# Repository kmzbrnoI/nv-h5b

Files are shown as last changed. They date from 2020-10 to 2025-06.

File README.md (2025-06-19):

NV-H5B
======

NV-H5B is a [S-COM](https://www.mtb-model.com/elektro/s-com.htm) receiver based
on [NV-7B](https://www.mtb-model.com/elektro/s-com-nav.htm). It is mounted
to the socket of a signal and displays signal code according to the received code
on data wire.

This repository contains KiCad schematics & pcb layout design as well as MCU
firmware source code.

## Basic features

 * 5 V power supply.
 * Mechanical compatibility with [NV-7D](https://www.mtb-model.com/elektro/s-com-nav.htm).
 * Receives [standard S-COM protocol](https://www.mtb-model.com/elektro/s-com.htm).
 * Separate resistor for each LED to unify brightness.
 * ATtiny25 main MCU.
 * Opensource & openhardware design.
 * [Supported signals (CZ)](signals.md).

## Recommended resistor values

### AŽD 70 signals by Josef Němeček

* Yellow: 4k7
* Red: 10k
* White: 22k
* Green: 2k2
* Blue: 22k

### AŽD 65 signals by Mr. Dvořáček (Pečky)

* Yellow: 1k
* Red: 10k
* White: 22k
* Green: 1k
* Blue: 47k

## Authors

 * [Jan Horacek](mailto:jan.horacek@kmz-brno.cz)

## License

PCBs are provided under [Creative Commons Attribution-ShareAlike 4.0
License](https://creativecommons.org/licenses/by-sa/4.0/) as openhardware
project. You may download any data, contribute to the project, create PCB
yourself or even sell it yourself.

Source code is provided under the [Apache License v2.0
](https://www.apache.org/licenses/LICENSE-2.0).

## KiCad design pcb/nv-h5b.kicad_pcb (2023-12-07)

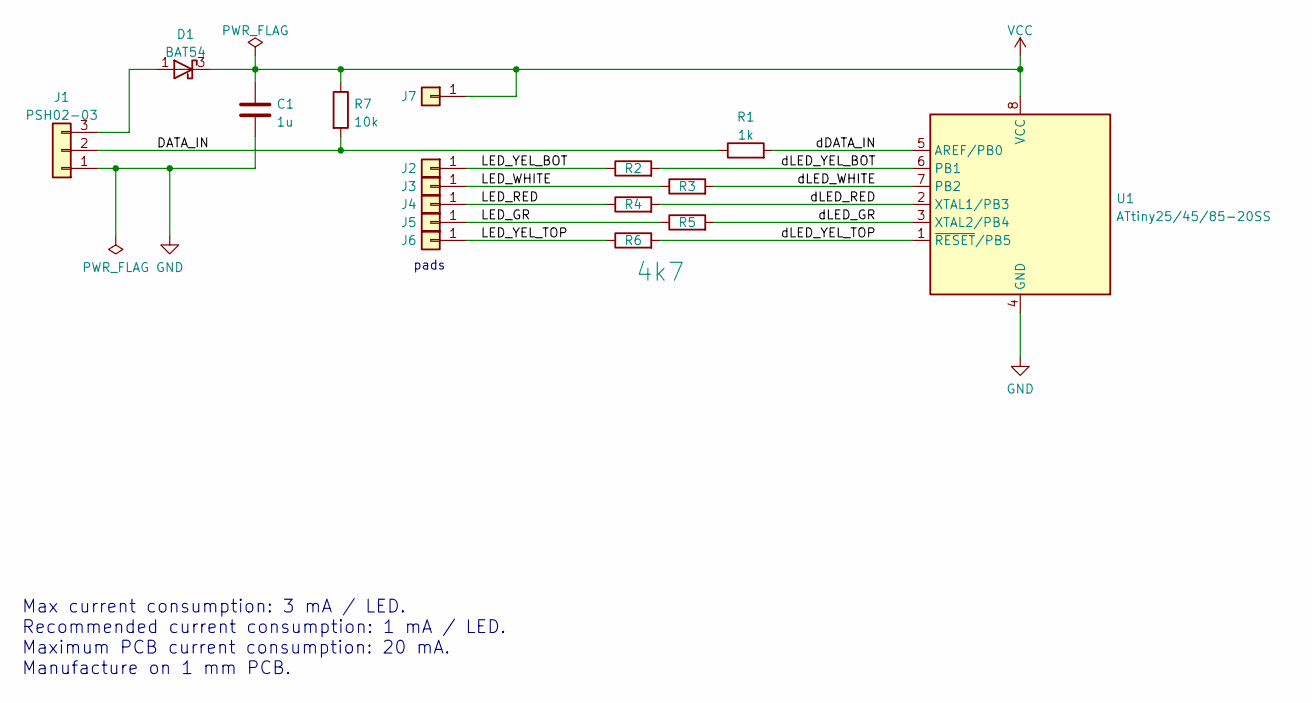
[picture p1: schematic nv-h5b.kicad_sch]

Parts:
C1: 1u; C_0805_2012Metric
D1: BAT54; SOT-23
J1: PSH02-03; PinHeader_1x03_P2.54mm_Horizontal
J2, J3, J4, J5, J6, J7: Conn_01x01; TestPoint_Keystone_5015_Micro-Minature
R1: 1k; R_0805_2012Metric
R2, R3, R4, R5, R6: 4k7; R_0805_2012Metric
R7: 10k; R_0805_2012Metric
U1: ATtiny25/45/85-20SS; SOIC-8_3.9x4.9mm_P1.27mm

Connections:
/DATA_IN: J1.2, R1.1, R7.2
/LED_GR: J5.1, R5.1
/LED_RED: J4.1, R4.1
/LED_WHITE: J3.1, R3.1
/LED_YEL_BOT: J2.1, R2.1
/LED_YEL_TOP: J6.1, R6.1
/dDATA_IN: R1.2, U1.5 (AREF/PB0)
/dLED_GR: R5.2, U1.3 (XTAL2/PB4)
/dLED_RED: R4.2, U1.2 (XTAL1/PB3)
/dLED_WHITE: R3.2, U1.7 (PB2)
/dLED_YEL_BOT: R2.2, U1.6 (PB1)
/dLED_YEL_TOP: R6.2, U1.1 (~RESET/PB5)
GND: C1.2, J1.1, U1.4 (GND)
unnamed: D1.1 (A), J1.3
VCC: C1.1, D1.3 (K), J7.1, R7.1, U1.8 (VCC)

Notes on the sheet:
Max current consumption: 3 mA / LED. Recommended current consumption: 1 mA / LED. Maximum PCB current consumption: 20 mA. Manufacture on 1 mm PCB.
pads

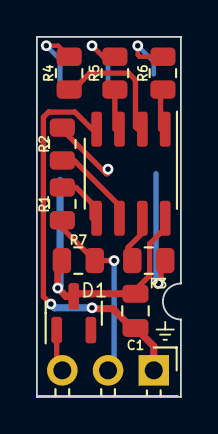
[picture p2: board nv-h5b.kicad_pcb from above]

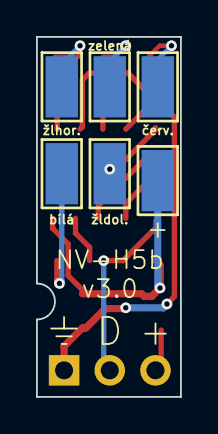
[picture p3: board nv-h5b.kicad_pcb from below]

Board: 2 copper layers, 8.0 x 20.0 mm, 17 parts (6 on the bottom side), 15 nets.

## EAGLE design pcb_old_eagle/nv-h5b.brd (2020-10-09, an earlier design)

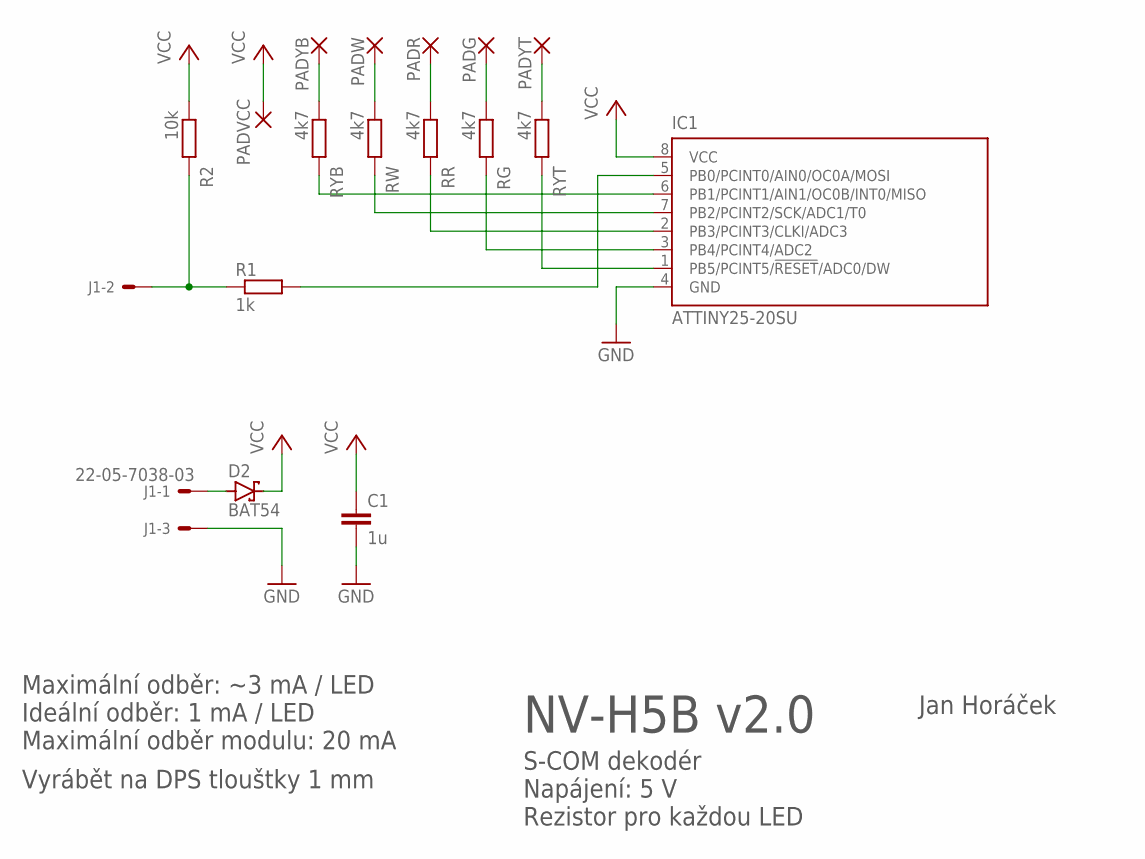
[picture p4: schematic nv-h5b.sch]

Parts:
C1: 1u; C0805
D2: BAT54; SOT23
IC1: ATTINY25-20SU; 8S1
J1: 22-05-7038-03; 7395-03
PADG: SMD3; SMD1,778-5,08
PADR: SMD3; SMD1,778-5,08
PADVCC: SMD3; SMD1,778-5,08
PADW: SMD3; SMD1,778-5,08
PADYB: SMD3; SMD1,778-5,08
PADYT: SMD3; SMD1,778-5,08
R1: 1k; R0805
R2: 10k; R0805
RG: 4k7; R0805
RR: 4k7; R0805
RW: 4k7; R0805
RYB: 4k7; R0805
RYT: 4k7; R0805

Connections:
DATAIN: J1.2, R1.1, R2.2
DATAIN_: IC1.5 (PB0/PCINT0/AIN0/OC0A/MOSI), R1.2
GND: C1.2, IC1.4 (GND), J1.3
GREEN: PADG.1, RG.1
unnamed: IC1.6 (PB1/PCINT1/AIN1/OC0B/INT0/MISO), RYB.2
unnamed: IC1.3 (PB4/PCINT4/ADC2), RG.2
unnamed: IC1.1 (PB5/PCINT5/!RESET!/ADC0/DW), RYT.2
unnamed: IC1.7 (PB2/PCINT2/SCK/ADC1/T0), RW.2
unnamed: IC1.2 (PB3/PCINT3/CLKI/ADC3), RR.2
RED: PADR.1, RR.1
VCC: C1.1, D2.3 (C), IC1.8 (VCC), PADVCC.1, R2.1
VIN: D2.1 (A), J1.1
WHITE: PADW.1, RW.1
YEL-BOT: PADYB.1, RYB.1
YEL-TOP: PADYT.1, RYT.1

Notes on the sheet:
Jan Horáček
NV-H5B v2.0
S-COM dekodér Napájení: 5 V Rezistor pro každou LED
Maximální odběr: ~3 mA / LED Ideální odběr: 1 mA / LED Maximální odběr modulu: 20 mA
Vyrábět na DPS tlouštky 1 mm

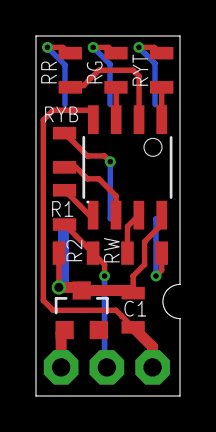
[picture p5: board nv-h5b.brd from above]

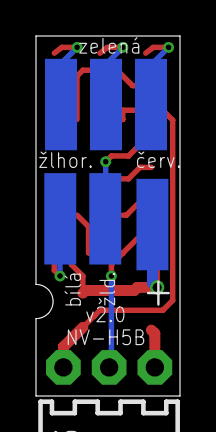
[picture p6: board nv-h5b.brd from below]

Board: 2 copper layers, 8.0 x 20.0 mm, 17 parts (7 on the bottom side), 15 nets.

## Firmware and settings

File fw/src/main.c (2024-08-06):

/* Main source file of NV-H5B S-COM receiver.
 */

#include <stdbool.h>
#include <util/delay.h>
#include <avr/interrupt.h>
#include <avr/io.h>
#include <avr/wdt.h>

#include "common.h"
#include "leds.h"
#include "pwm.h"
#include "signal.h"
#include "decode.h"

///////////////////////////////////////////////////////////////////////////////

int main();
static inline void init(void);
static inline void detect_signal_type(void);
static inline void init_led_test(void);

///////////////////////////////////////////////////////////////////////////////

const char version[16] __attribute__ ((section(".fwversion"))) = "NV-H5B   FW v1.2";
volatile uint8_t counter_100us = 0;

///////////////////////////////////////////////////////////////////////////////

int main() {
	init();

	while (true) {
		wdt_reset();
	}
}

void init(void) {
	ACSR |= ACD;  // analog comparator disable

	detect_signal_type();
	led_init();
	decode_init();

	// Setup timer 0
	TCCR0A |= 1 << WGM01; // CTC mode
	TCCR0B |= 1 << CS01; // no prescaler
	TIMSK |= 1 << OCIE0A; // enable compare match A
	OCR0A = 99;

	sei(); // enable interrupts globally (receive code during test)

	init_led_test();

	// If valid code already received (during test), set it directly, else set PN
	set_signal_code((last_received_code != 0xFF) ? last_received_code : 8);
	on_received = set_signal_code;

	wdt_enable(WDTO_250MS);
}

void init_led_test(void) {
	led_set(LED_YELLOW_TOP, true);
	_delay_ms(300);
	led_set(LED_YELLOW_TOP, false);
	led_set(LED_GREEN, true);
	_delay_ms(300);
	led_set(LED_GREEN, false);
	if (signal_set == stMain) {
		led_set(LED_RED, true);
		_delay_ms(300);
		led_set(LED_RED, false);
	}
	led_set(LED_WHITE, true);
	_delay_ms(300);
	led_set(LED_WHITE, false);
	if (signal_set == stMain) {
		led_set(LED_YELLOW_BOTTOM, true);
		_delay_ms(300);
		led_set(LED_YELLOW_BOTTOM, false);
	}
	_delay_ms(500);
}

void detect_signal_type(void) {
	// repeater = red and bottom yellow wires connected
	DDRB |= LED_RED; // pin as output
	PORTB &= ~(LED_RED); // zero to output
	PORTB |= LED_YELLOW_BOTTOM; // pull-up enable
	_delay_ms(1);
	signal_set = (PINB & LED_YELLOW_BOTTOM) ? stMain : stRepeater;
}

ISR(TIM0_COMPA_vect) {
	// Timer 0 @ 10 kHz (period 100 us)
	counter_100us++;

	static uint8_t counter_10ms = 0;
	counter_10ms++;
	if (counter_10ms >= 100) {
		counter_10ms = 0;
		signal_update_10ms();
	}

	pwm_update();
	decode_update();
}

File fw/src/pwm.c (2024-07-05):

#include <stdint.h>
#include <stdbool.h>

#include "pwm.h"
#include "leds.h"
#include "common.h"

#define RAMP_UP_PERIOD 32 // should a divisor of 256
#define RAMP_DOWN_PERIOD 64 // should a divisor of 256
#define PWM_FULL 20

volatile uint8_t ramp_up_mask = 0;
volatile uint8_t ramp_down_mask = 0;
volatile uint8_t ramp_up_shift;
volatile uint8_t ramp_down_shift;

void pwm_update(void) {
	volatile static uint8_t pwm_counter = 0;

	if (ramp_up_mask != 0) {
		led_set(ramp_up_mask, pwm_counter <= ramp_up_shift);
		if (counter_100us % RAMP_UP_PERIOD == 0) {
			ramp_up_shift++;
			if (ramp_up_shift >= PWM_FULL-1) {
				led_set(ramp_up_mask, true);
				ramp_up_mask = 0; // end
			}
		}
	}

	if (ramp_down_mask != 0) {
		led_set(ramp_down_mask, pwm_counter <= ramp_down_shift);
		if (counter_100us % RAMP_DOWN_PERIOD == 0) {
			ramp_down_shift--;
			if (ramp_down_shift <= 1) {
				led_set(ramp_down_mask, false);
				ramp_down_mask = 0; // end
			}
		}
	}

	pwm_counter++;
	if (pwm_counter >= PWM_FULL)
		pwm_counter = 0;
}

void ramp_up(uint8_t mask) {
	if (mask == 0)
		return;
	ramp_down_mask &= ~mask;
	if (ramp_up_mask != 0)
		led_set(ramp_up_mask, true);
	ramp_up_mask = mask;
	ramp_up_shift = 0;
}

void ramp_down(uint8_t mask) {
	if (mask == 0)
		return;
	ramp_up_mask &= ~mask;
	if (ramp_down_mask != 0)
		led_set(ramp_down_mask, false);
	ramp_down_mask = mask;
	ramp_down_shift = PWM_FULL;
}

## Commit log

2020-08-15 Initial version of schematics & PCB.
    [nv-h5b.brd, nv-h5b.sch]
2020-08-15 Increase main capacitor.
    [nv-h5b.brd]
2020-08-15 Increase LED resistors (~ max. 3 mA/ LED).
    [nv-h5b.brd, nv-h5b.sch]
2020-08-15 Add info about power consumption.
    [nv-h5b.sch]
2020-08-15 Use vector font for silkscreen.
    [nv-h5b.brd]
2020-08-15 Move pcb layout to separate repository.
    [nv-h5b.brd, nv-h5b.sch]
2020-08-15 PCB: add version.
    [nv-h5b.brd, nv-h5b.sch]
2020-08-15 fw: add leds basic functions.
2020-08-15 Add pwm module.
2020-08-15 Add test LED setting.
2020-08-15 Setup timer 0 @ 1 kHz.
2020-08-15 Balance PWM & timer frequency.
2020-08-15 Make PWM for all LEDs work.
2020-08-15 Pwm: use #define to spare RAM.
2020-08-17 sch: use ATtiny25.
    [nv-h5b.brd, nv-h5b.sch]
2020-08-17 Fix really silly bug.
    [pwm.c]
2020-08-17 Add proper fuses & F_CPU to Makefile.
2020-08-17 Switch MSB & LSB when receiving signal.
2020-08-18 Tune PWM parameters for smaller period.
2020-08-18 Do not interfere ramps.
    [pwm.c]
2020-08-18 Fix flash code changes.
    [main.c]
2020-08-18 Remap LED for real MCU.
2020-08-21 Set LED properly when PWM rewrite.
2020-08-21 Move code to avoid race condition due to interrupt.
    [pwm.c]
2020-09-22 Opravit orientaci vstupniho konektoru.
    Bylo opacne GND & VCC.
    [nv-h5b.brd, nv-h5b.sch]
2020-10-09 Make side drill smaller.
    [nv-h5b.brd]
2023-03-05 Move 'pcb' to 'old' directory (new PCB in KiCad).
    [nv-h5b.brd, nv-h5b.sch]
2023-03-05 Update Eagle version.
    [nv-h5b.sch]
2023-03-05 Add empty KiCad project.
    [nv-h5b.kicad_pcb, nv-h5b.kicad_sch]
2023-03-05 Finalize schematics.
    [nv-h5b.kicad_pcb, nv-h5b.kicad_sch]
2023-03-05 Route PCB.
    [nv-h5b.kicad_pcb, nv-h5b.kicad_sch]
2023-03-05 kikit panelize: add tolerance.
    [nv-h5b.kicad_pcb]
2023-03-09 Add part names to silkscreen.
    [nv-h5b.kicad_pcb]
2023-03-09 Add *.kicad_prl to .gitignore.
    [nv-h5b.kicad_pcb]
2023-03-09 Create tester PCB: copy from NV-H5B pcb.
    [nv-h5b-tester.kicad_pcb, nv-h5b-tester.kicad_sch]
2023-03-09 Tester: add LEDs to chematics, route PCB.
    [nv-h5b-tester.kicad_pcb, nv-h5b-tester.kicad_sch]
2023-03-12 Use thin top width.
    Because signal must fit in tracks profile.
    [nv-h5b-tester.kicad_pcb]
2023-03-15 NV-H5B tester -> NV-H5T.
    [nv-h5t.kicad_pcb, nv-h5t.kicad_sch]
2023-03-15 Add 3V3 stabilizer, so NV-H5T supports both 5V & 12V power supply.
    [nv-h5t.kicad_pcb, nv-h5t.kicad_sch]
2023-03-15 Make panel.
    [nv-h5t.kicad_pcb]
2023-03-19 Note possible alterantive versions of MCU.
    [nv-h5b.kicad_sch, nv-h5t.kicad_sch]
2023-03-21 Add AZD 70 resistor values.
2023-12-07 Remove silkscreen of main connector outside of PCB.
    [nv-h5b.kicad_pcb]
2023-12-20 Add fuses.conf.
2024-07-04 Delay turning the red LED off.
    In reality, the red light is turned off only after a successful validation
    of the allowing aspect.
2024-07-05 Add initial led test.
2024-07-07 Decrease red LED turnoff delay to 150 ms.
    This a more realisitc behavior.
    Previous value: ~800 ms.
2024-07-20 README: add AZD 65 recommended resistor values.
2024-08-03 Use new fuses.conf format (minipro v0.7).
2024-08-03 README: update AZD 65 recommended resistors.
2024-08-09 AZD65: add recommended blue resistor.
2024-12-04 README: add blue LED resistor value (22k).
2025-07-20 Disable spare peripherals to reduce power consumption.
2026-07-16 Update fuses.conf.
2026-10-16 Distinguish programming flash & fuses.
2026-10-16 Avoid calling code directly from interrupt.
    * Use interrupt request flags instead.
    * Save MCU memory usage due to removal of 'volatile'.

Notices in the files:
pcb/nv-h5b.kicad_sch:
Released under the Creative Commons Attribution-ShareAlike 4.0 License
